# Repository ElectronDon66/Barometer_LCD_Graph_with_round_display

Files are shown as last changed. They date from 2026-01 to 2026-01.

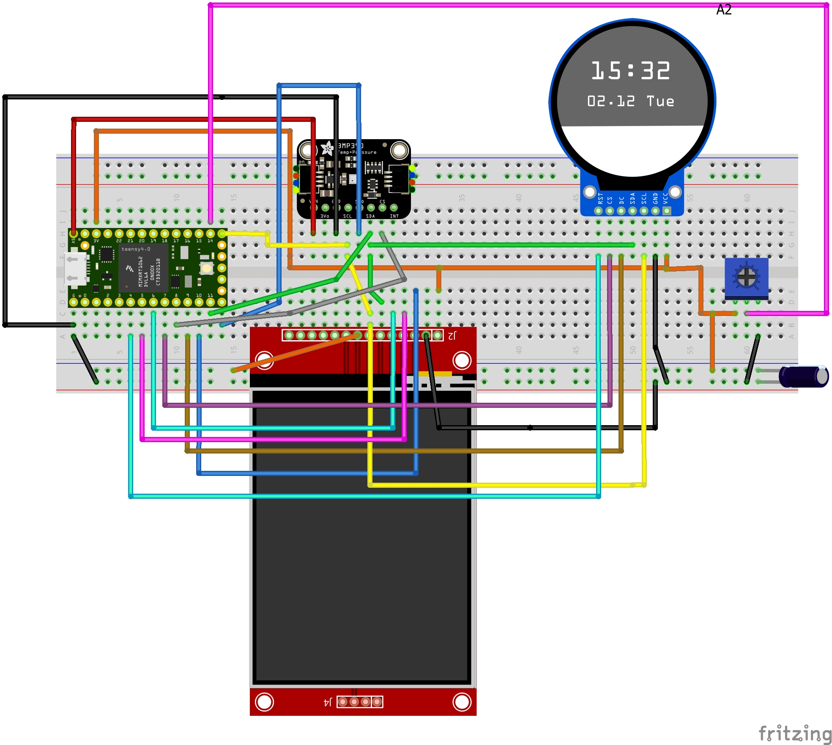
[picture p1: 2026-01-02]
Cartesian Barometer_fritz_schematic.jpg

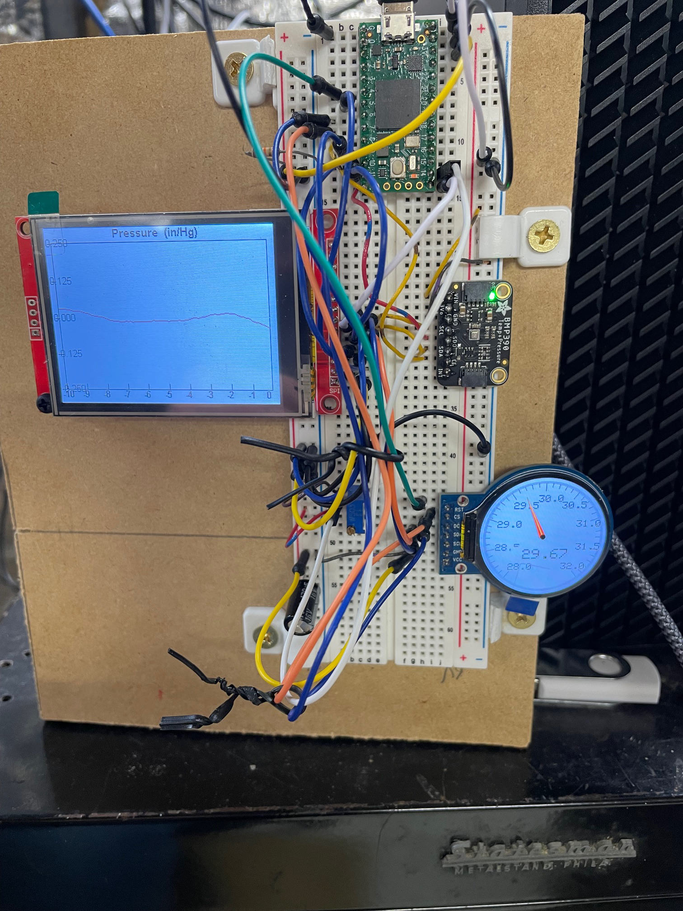
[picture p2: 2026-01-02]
PhotoB.jpeg

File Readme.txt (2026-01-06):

This project repository contains a schematic , Bill of Material ,picture and Arduino code for a graphing barometer.
The project has two displays:
A 320 x 240 ILI9341 TFT LCD display that shows the last 10 hours of the barometric pressure (2.8 inch diagonal) 
A round GC9A01 (1.28 inch round) LCD display 
The processor used is a Teensy 4.0 .
 The air pressure sensor is an Adafruit BMP390. A potentiometer allows you to calibrate the barometric pressure reading to a local airport or weather station. 
The potentiometer is creating an analog voltage read by the Teensy 4.0 that is proportional to your altitude (above sea level) offset as all barometers
are typically set to read the barometric pressure as if you location was located at sea level. To set the pot,  power up the circuitry and watch the round 
current barometric pressure reading. Obtain your local barometric pressure (cell phone weather ) or local airport altimeter setting. rotate the pot until the 
needle on the round display is the same as the local barometric pressure and you are done.
The round display updates once a second. The graphing LCD takes data every 6 minutes, but only updates the display once an hour. Upon initial powerup  the  graphing
display takes the current pressure reading and populates the whole display with just the current reading. 
Pressure data is in inches of mercury (In/Hg). 
The graphing display shows relative pressure changes based on the average pressure with a 10 point average. This is so you can see small pressure changes.
The round display is absolute pressure so it extends from 28 In/Hg up to 32 In/Hg. 

I used Arduino's IDE to write the code. In order to run the code on a teensy 4.0 microcontroller you'll  also need to install the Teensy URL in the Arduino board manager (preferences).Probably the easiest way for you to do this is go to https://www.pjrc.com/teensy/tutorial.html and follow the instructions to load the Teensyduino into the Arduino boards manager. This is a critical step to use the Teensy. Essentially you'll be opening the Arduino board manager folder, searching for Teensy  by Paul Stoffregen and clicking install. The tutorial at the PJRC site will help you to do this. Then don't forget to go to Arduino IDE and select the Teensy 4.0 under the tools tab.  There are also some youtube videos that show how to do this but it's not all that difficult. See my Youtube video at 
https://youtu.be/VZpJxaQQ_cM

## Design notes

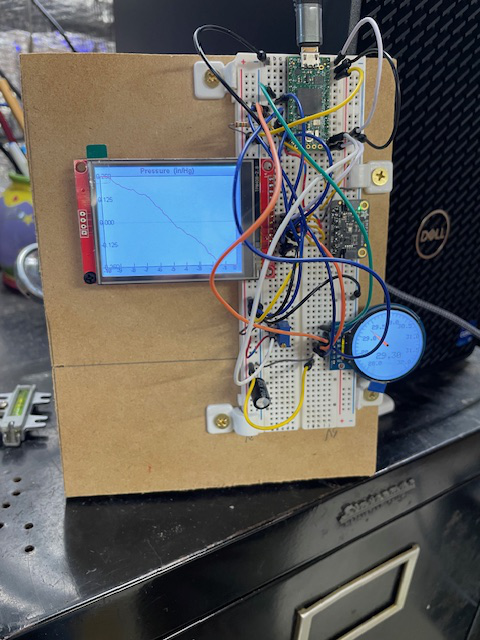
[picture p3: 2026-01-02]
Photo.jpeg

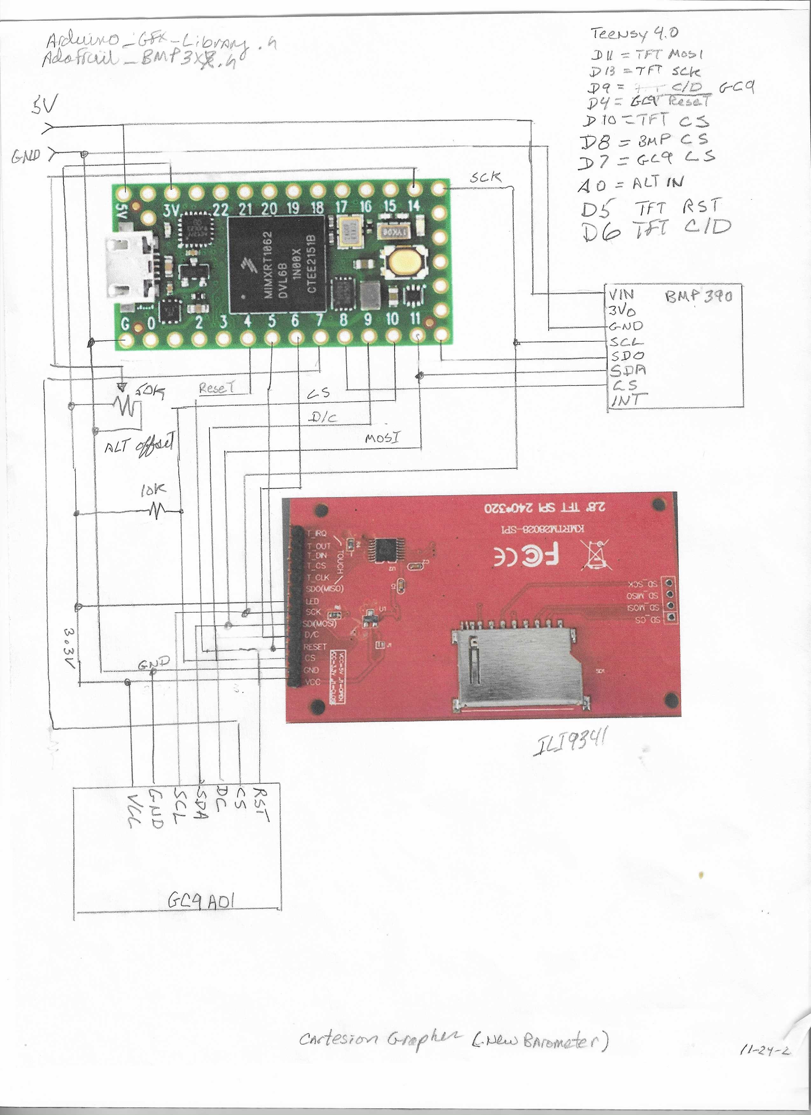
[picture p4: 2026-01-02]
Scan_20251211.jpg

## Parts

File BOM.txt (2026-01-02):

Bill of Materials 

All parts were purchased on Amazon 

Teensy, 4.0 Microcontroller (PRJC)
DIANN, 2.8" TFT SPI 240 x 320 (ILI9341 driver)
HiLetgo, 1.28" TFT LCD display (GC9A01 driver) 
Adafruit,  BMP390 pressure sensor 
470 uF electrolytic cap 
50 K Ohm 10 turn trimmer potentiometer ,Electronics Salon

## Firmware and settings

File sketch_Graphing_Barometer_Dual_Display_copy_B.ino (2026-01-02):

// Converted sketch: GC9A01 (Arduino_GFX) + ILI9341_t3n (plot)
// Only the ILI display was converted to ILI9341_t3n (Option A)
// Needed to load mjs513 fonts to get display looking good
//Sketch is working , looks good
// DEW 12/12/25 Release 


#include <Arduino_GFX_Library.h>   // for GC9A01 round display
#include <Adafruit_BMP3XX.h>
#include <SPI.h>
#include <elapsedMillis.h>
#include <ILI9341_t3n.h>          // NEW: ILI display library
#include <font_Arial.h>           // custom fonts from github.com/mjs513 
#include "font_ArialBold.h"

// ---------------------------
// PIN DEFINITIONS
// ---------------------------
#define BMP_CS       8
#define TFT_CS       7
#define TFT_DC       9
#define TFT_RST      4
#define ANALOG_OFFSET_PIN A0

// ILI (rectangular plot)
#define ILI_CS    10  
#define ILI_DC     6
#define ILI_RST    5

// Colors (RGB565)
#define C_WHITE 0xFFFF
#define C_BLACK 0x0000
#define C_RED   0xF800
#define C_LTGREY 0xE71C
#define C_LTYELLOW 0xF7EE
#define C_BLUE  0x001F

// ---------------------------
// GLOBAL OBJECTS
// ---------------------------
// BMP390 + GC9A01 remain unchanged
Adafruit_BMP3XX bmp;   // SPI BMP390
Arduino_DataBus *bus = new Arduino_HWSPI(TFT_DC, TFT_CS);
Arduino_GFX *gfx = new Arduino_GC9A01(bus, TFT_RST, 0, true);
Arduino_Canvas_Indexed *canvas = new Arduino_Canvas_Indexed(240, 240, gfx);

// NEW: create ILI9341_t3n object (uses same hardware SPI bus)
ILI9341_t3n tft_ili = ILI9341_t3n(ILI_CS, ILI_DC, ILI_RST);

// ---------------------------
// TIMERS
// ---------------------------
elapsedMillis t_1sec = 0;
elapsedMillis t_0p1hr = 0;
elapsedMillis t_1hr = 0;

// ---------------------------
// GAUGE SETTINGS
// ---------------------------
float minInHg = 28.0;
float maxInHg = 32.0;
float lastAngle = -140;

// ---------- Plot buffer & settings -------
const int PLOT_POINTS = 100;             // 100 points over 10 hours (0.1 hr spacing)
float pressureBuffer[PLOT_POINTS];
int bufferIndex = 0;
bool bufferFilled = false;

// Plot area margins (on ILI 320x240)
const int PLOT_W = 300;
const int PLOT_H = 200;
const int PLOT_X = 10;    // left margin
const int PLOT_Y = 20;    // top margin

const float YSPAN = 0.25f; // +/-0.25 inHg

// Forward declarations
void initPlotBuffer(float initVal);
void samplePressureToBuffer();
float bufferAverage();
void drawPressurePlot();

// ---------------------------
// UTILITY FUNCTIONS
// ---------------------------
float pressureToAngle(float p) {
  float ratio = (p - minInHg) / (maxInHg - minInHg);
  ratio = constrain(ratio, 0, 1);
  return -140 + ratio * 280 - 90; // match dial rotation
}

float readPressureInHg() {
  if (!bmp.performReading()) return -1;
  float inHg = (bmp.pressure / 100.0) * 0.02953;

  int raw = analogRead(ANALOG_OFFSET_PIN);
  float offset = map(raw, 0, 4095, -1000, 1000) / 1000.0;

  return inHg + offset;
}

// ---------------------------
// GAUGE DRAWING (unchanged)
// ---------------------------
void drawGaugeFace() {
  canvas->fillScreen(C_WHITE);
  int cx = 120, cy = 120;
  int r = 110;

  // --- Draw shadow on the outer perimeter ---
  for (int s = 0; s < 5; s++) {            // 5 layers of shadow
    int shadowRadius = r + s;               // slightly larger than main radius
    canvas->drawCircle(cx, cy, shadowRadius, C_LTGREY);
  }

  float majorStep = 0.5;   // Major ticks every 0.5 inHg
  float minorStep = 0.1;   // Minor ticks every 0.1 inHg
  float tol = 0.01;        // Tolerance for floating-point comparison

  // Draw all ticks
  for (float value = minInHg; value <= maxInHg + 0.01; value += minorStep) {
    float angle = -140 + ((value - minInHg) / (maxInHg - minInHg)) * 280 - 90;
    float rad = angle * 0.0174533;

    // Determine if major or minor tick
    bool isMajor = (fmod(value, majorStep) < tol) || (majorStep - fmod(value, majorStep) < tol);
    int tickLength = isMajor ? 15 : 8;       // Major ticks longer

    int x1 = cx + cos(rad)*(r - tickLength);
    int y1 = cy + sin(rad)*(r - tickLength);
    int x2 = cx + cos(rad)*r;
    int y2 = cy + sin(rad)*r;

    canvas->drawLine(x1, y1, x2, y2, C_BLACK);

    // Draw number for major ticks
    if (isMajor) {
      char buf[10]; dtostrf(value, 4, 1, buf);

      // Offset numbers slightly beyond major tick
      int xt = cx + cos(rad)*(r - 30);  // 10 pixels beyond the tick line
      int yt = cy + sin(rad)*(r - 30);

      canvas->setCursor(xt - 12, yt - 6);
      canvas->setTextColor(C_BLACK);
      canvas->setTextSize(2);
      canvas->print(buf);
    }
  }

  canvas->fillCircle(cx, cy, 5, C_BLACK);
}

void drawNeedle(float angleDeg)
{
  int cx = 120, cy = 120;
  int length = 90;

  float rad = angleDeg * 0.0174533;

  // Needle tip
  int tipX = cx + cos(rad) * length;
  int tipY = cy + sin(rad) * length;

  // Needle base width
  int baseWidth = 6;

  // Calculate perpendicular for the base
  float perpRad = rad + 1.5708; // 90 degrees in radians
  int x1 = cx + cos(perpRad) * baseWidth;
  int y1 = cy + sin(perpRad) * baseWidth;
  int x2 = cx - cos(perpRad) * baseWidth;
  int y2 = cy - sin(perpRad) * baseWidth;

  // Draw filled triangle (needle)
  canvas->fillTriangle(x1, y1, x2, y2, tipX, tipY, C_RED);

  // Optional: draw thin center highlight
  int hx = cx + cos(rad) * length;
  int hy = cy + sin(rad) * length;
  canvas->drawLine(cx, cy, hx, hy, C_LTYELLOW); // subtle highlight

  // Draw circular hub over base
  canvas->fillCircle(cx, cy, 5, C_BLACK);
}

void drawDigitalReadout(float p) {
  char buf[16]; dtostrf(p, 6, 2, buf);
  canvas->fillRect(60, 140, 120, 30, C_WHITE);
  canvas->setTextColor(C_BLACK);
  canvas->setTextSize(3);
  canvas->setCursor(65, 145);
  canvas->print(buf);
}

void updateNeedleSmooth(float newAngle, float pressureInHg) {
  int steps = 12;
  float step = (newAngle - lastAngle)/steps;

  for (int i = 1; i <= steps; i++) {
    float a = lastAngle + step*i;
    drawGaugeFace();
    drawNeedle(a);
    drawDigitalReadout(pressureInHg);
    canvas->flush();
    delay(10); // small delay, less blocking
  }
  lastAngle = newAngle;
}

// ---------------------------
// PLOT BUFFER FUNCTIONS
// ---------------------------
void initPlotBuffer(float initVal) {
  for (int i = 0; i < PLOT_POINTS; ++i) pressureBuffer[i] = initVal;
  bufferIndex = 0;
  bufferFilled = true;
}

// Called every 0.1 hr (6 minutes) by timer B (t_0p1hr)
void samplePressureToBuffer() {
  float p = readPressureInHg();
  if (p <= 0) return; // ignore bad reads

  pressureBuffer[bufferIndex] = p;
  bufferIndex++;
  if (bufferIndex >= PLOT_POINTS) {
    bufferIndex = 0;
    bufferFilled = true;
  }
}

// Compute average of buffer
float bufferAverage() {
  float sum = 0;
  for (int i = 0; i < PLOT_POINTS; ++i) sum += pressureBuffer[i];
  return sum / (float)PLOT_POINTS;
}

// Map a relative pressure (p - avg) to pixel Y (centered)
int mapRelativeToY(float relative) {
  // relative in [-YSPAN, +YSPAN]
  if (relative > YSPAN) relative = YSPAN;
  if (relative < -YSPAN) relative = -YSPAN;
  // centerY at middle of plot area
  int centerY = PLOT_Y + PLOT_H / 2;
  // map +YSPAN -> PLOT_Y (top), -YSPAN -> PLOT_Y+PLOT_H (bottom)
  float frac = (relative + YSPAN) / (2.0f * YSPAN); // 0..1
  int y = PLOT_Y + (int)((1.0f - frac) * PLOT_H + 0.5f);
  return y;
}

// Draw axes, ticks, and the plot line on the ILI display (using ILI9341_t3n)
void drawPressurePlot() {
  // Use direct tft_ili drawing (RGB565 colors)
  tft_ili.fillScreen(C_LTGREY);

  // Draw plot border and background
  tft_ili.drawRect(PLOT_X - 1, PLOT_Y - 1, PLOT_W + 2, PLOT_H + 2, C_BLACK);
  tft_ili.fillRect(PLOT_X, PLOT_Y, PLOT_W, PLOT_H, C_WHITE);

  // X spacing and center line
  float xSpacing = (float)PLOT_W / (PLOT_POINTS - 1);
  int centerY = PLOT_Y + PLOT_H / 2;
  tft_ili.drawLine(PLOT_X, centerY, PLOT_X + PLOT_W, centerY, C_LTGREY);

  // X-axis ticks and labels (-10 -> 0 hours)
  
  tft_ili.setFont(Arial_9_Bold);
  tft_ili.setTextSize(1);           // fractional size (if supported)
 
  tft_ili.setTextColor(C_BLACK);
  
  for (int hr = -10; hr <= 0; hr++) {
    int sampleIndex = (hr + 10) * 10;  // hr=-10 => 0, hr=0 => 100 -> clamp
    if (sampleIndex < 0) sampleIndex = 0;
    if (sampleIndex > PLOT_POINTS - 1) sampleIndex = PLOT_POINTS - 1;
    float xf = PLOT_X + sampleIndex * xSpacing;
    int xi = (int)(xf + 0.5f);

    // tick
    tft_ili.drawLine(xi, PLOT_Y + PLOT_H, xi, PLOT_Y + PLOT_H - 8, C_BLACK);

    // label (centered approximation)
    char lbl[8];
    itoa(hr, lbl, 10);
    // approximate centering; adjust if needed
    tft_ili.setCursor(xi - 8, PLOT_Y + PLOT_H + 2);
    tft_ili.print(lbl);
  }

  // Y axis ticks and labels at +0.25, +0.125, 0, -0.125, -0.25
  
  tft_ili.setFont(Arial_9);
  tft_ili.setTextSize(1);
  float ymarks[] = { YSPAN, YSPAN/2.0f, 0.0f, -YSPAN/2.0f, -YSPAN };
  for (int i = 0; i < 5; ++i) {
    int yy = mapRelativeToY(ymarks[i]);
    tft_ili.drawLine(PLOT_X - 6, yy, PLOT_X, yy, C_BLACK);

    char buf[12];
    dtostrf(ymarks[i], 5, 3, buf);
    tft_ili.setCursor(2, yy - 6);
    tft_ili.print(buf);
  }

  // Draw polyline of relative pressure = sample - avg
  float avg = bufferAverage();
  int idx = bufferIndex; // oldest sample
  int prevX = PLOT_X;
  int prevY = mapRelativeToY(pressureBuffer[idx] - avg);

  for (int i = 0; i < PLOT_POINTS; ++i) {
    float p = pressureBuffer[idx];
    float rel = p - avg;
    float xf = PLOT_X + i * xSpacing;
    int xi = (int)(xf + 0.5f);
    int yi = mapRelativeToY(rel);

    if (i > 0) {
      tft_ili.drawLine(prevX, prevY, xi, yi, C_RED); // trace color
    }
    prevX = xi; prevY = yi;

    idx++;
    if (idx >= PLOT_POINTS) idx = 0;
  }

  // Title
  tft_ili.setCursor(PLOT_X, 2);

  tft_ili.setFont(Arial_11_Bold);
  tft_ili.setTextSize(1);
  tft_ili.setTextColor(C_BLACK);
  tft_ili.print("                      Pressure  (in/Hg)  ");
}

// ---------------------------
// SETUP
// ---------------------------
void setup() {
  Serial.begin(115200);
  while (!Serial && millis() < 3000);

  Serial.println("Setup start");
  analogReadResolution(12);

  pinMode(TFT_RST, OUTPUT);
  digitalWrite(TFT_RST, LOW);
  delay(50);
  digitalWrite(TFT_RST, HIGH);

  // Reset the ILI
  pinMode(ILI_RST, OUTPUT);
  digitalWrite(ILI_RST, LOW); delay(50); digitalWrite(ILI_RST, HIGH);

  // initialize GC9A01 (main round gauge)
  gfx->begin();
  canvas->begin();

  // initialize ILI9341_t3n (rectangular plot)
  tft_ili.begin();
  tft_ili.setRotation(1);
  tft_ili.invertDisplay(false); // fix for your panel variant

  Serial.println("Display initialized");

  // BMP init AFTER displays (prevents blocking issues)
  if (!bmp.begin_SPI(BMP_CS)) {
    Serial.println("BMP390 not found!");
    while(1);
  }

  bmp.setTemperatureOversampling(BMP3_OVERSAMPLING_8X);
  bmp.setPressureOversampling(BMP3_OVERSAMPLING_4X);
  bmp.setIIRFilterCoeff(BMP3_IIR_FILTER_COEFF_3);
  bmp.setOutputDataRate(BMP3_ODR_50_HZ);

  drawGaugeFace();
  drawNeedle(lastAngle);
  drawDigitalReadout(minInHg);
  canvas->flush();

  Serial.println("Setup complete");
 float initial = readPressureInHg();
 int ti =0;
 while (ti< 4) {
  initial = readPressureInHg(); ti++;  // throw away first 4 readings for IIR filter 
 }

  
    

  // initialize and prefill buffer with a current reading
   initial = readPressureInHg();
  if (initial <= 0) initial = minInHg; // fallback
  initPlotBuffer(initial);
  
  
  // Print initial reading for trouble shooting 
  Serial.print("Initial reading");
  Serial.println(initial);
  
  drawPressurePlot();
}

// ---------------------------
// MAIN LOOP
// ---------------------------
void loop() {
  if (t_1sec >= 1000) {
    t_1sec = 0;
    float p = readPressureInHg();
    if (p > 0) {
      float angle = pressureToAngle(p);
      updateNeedleSmooth(angle, p);
      Serial.print("Pressure: "); Serial.println(p);
    }
  }

  // 0.1 hr timer -> sampling (6 minutes)
  if (t_0p1hr >= 360000) {
    t_0p1hr = 0;
    samplePressureToBuffer();
  }

  // 1 hr timer -> update plot display
  if (t_1hr >= 3600000) {
    t_1hr = 0;
    drawPressurePlot();
  }
}
